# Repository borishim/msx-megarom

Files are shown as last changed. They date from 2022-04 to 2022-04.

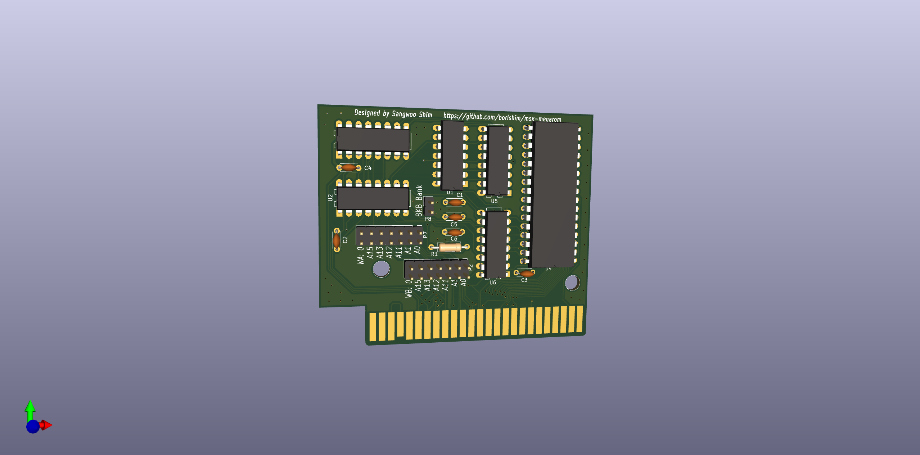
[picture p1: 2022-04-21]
megarom.png

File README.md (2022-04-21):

# msx-megarom
MSX megarom cartridge pcb (kicad)

There are three jumpers to set:
- P8: put a jumper for 8kB bank, otherwise 16kB
- P7 and P2: bank selection bits (WA and WB). Depends on the mapper type.

For example,
```
                           8kB WA  WB
                     ASC8: YES A11 A12
                    ASC16: NO  A12 0
                 Generic8: YES A13 A15
                Generic16: NO  A15 0
               Konami SCC: YES A13 A15
            Konami no SCC: YES A13 A15
Super Game World 30/64/80: YES A0  A1
            Super Pierrot: NO  A12 0
```
Also take a look https://www.msx.org/wiki/MegaROM_Mappers

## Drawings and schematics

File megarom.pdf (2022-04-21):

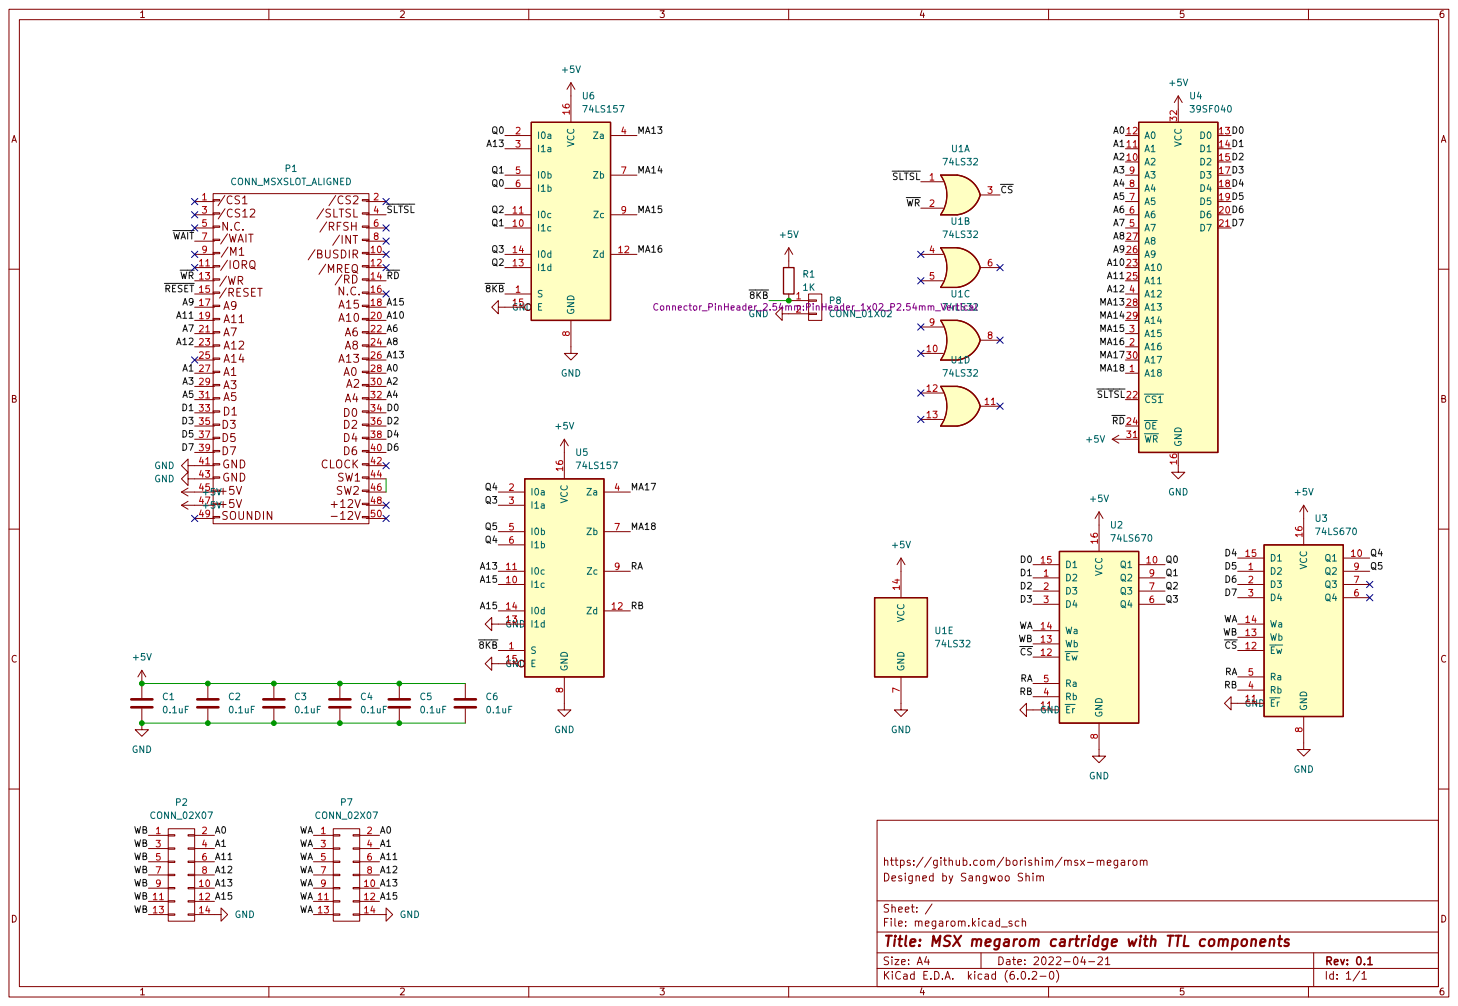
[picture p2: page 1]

https://github.com/borishim/msx-megarom
File: megarom.kicad_sch Sheet: / Designed by Sangwoo Shim

Id: 1/1 Title: MSX megarom cartridge with TTL components

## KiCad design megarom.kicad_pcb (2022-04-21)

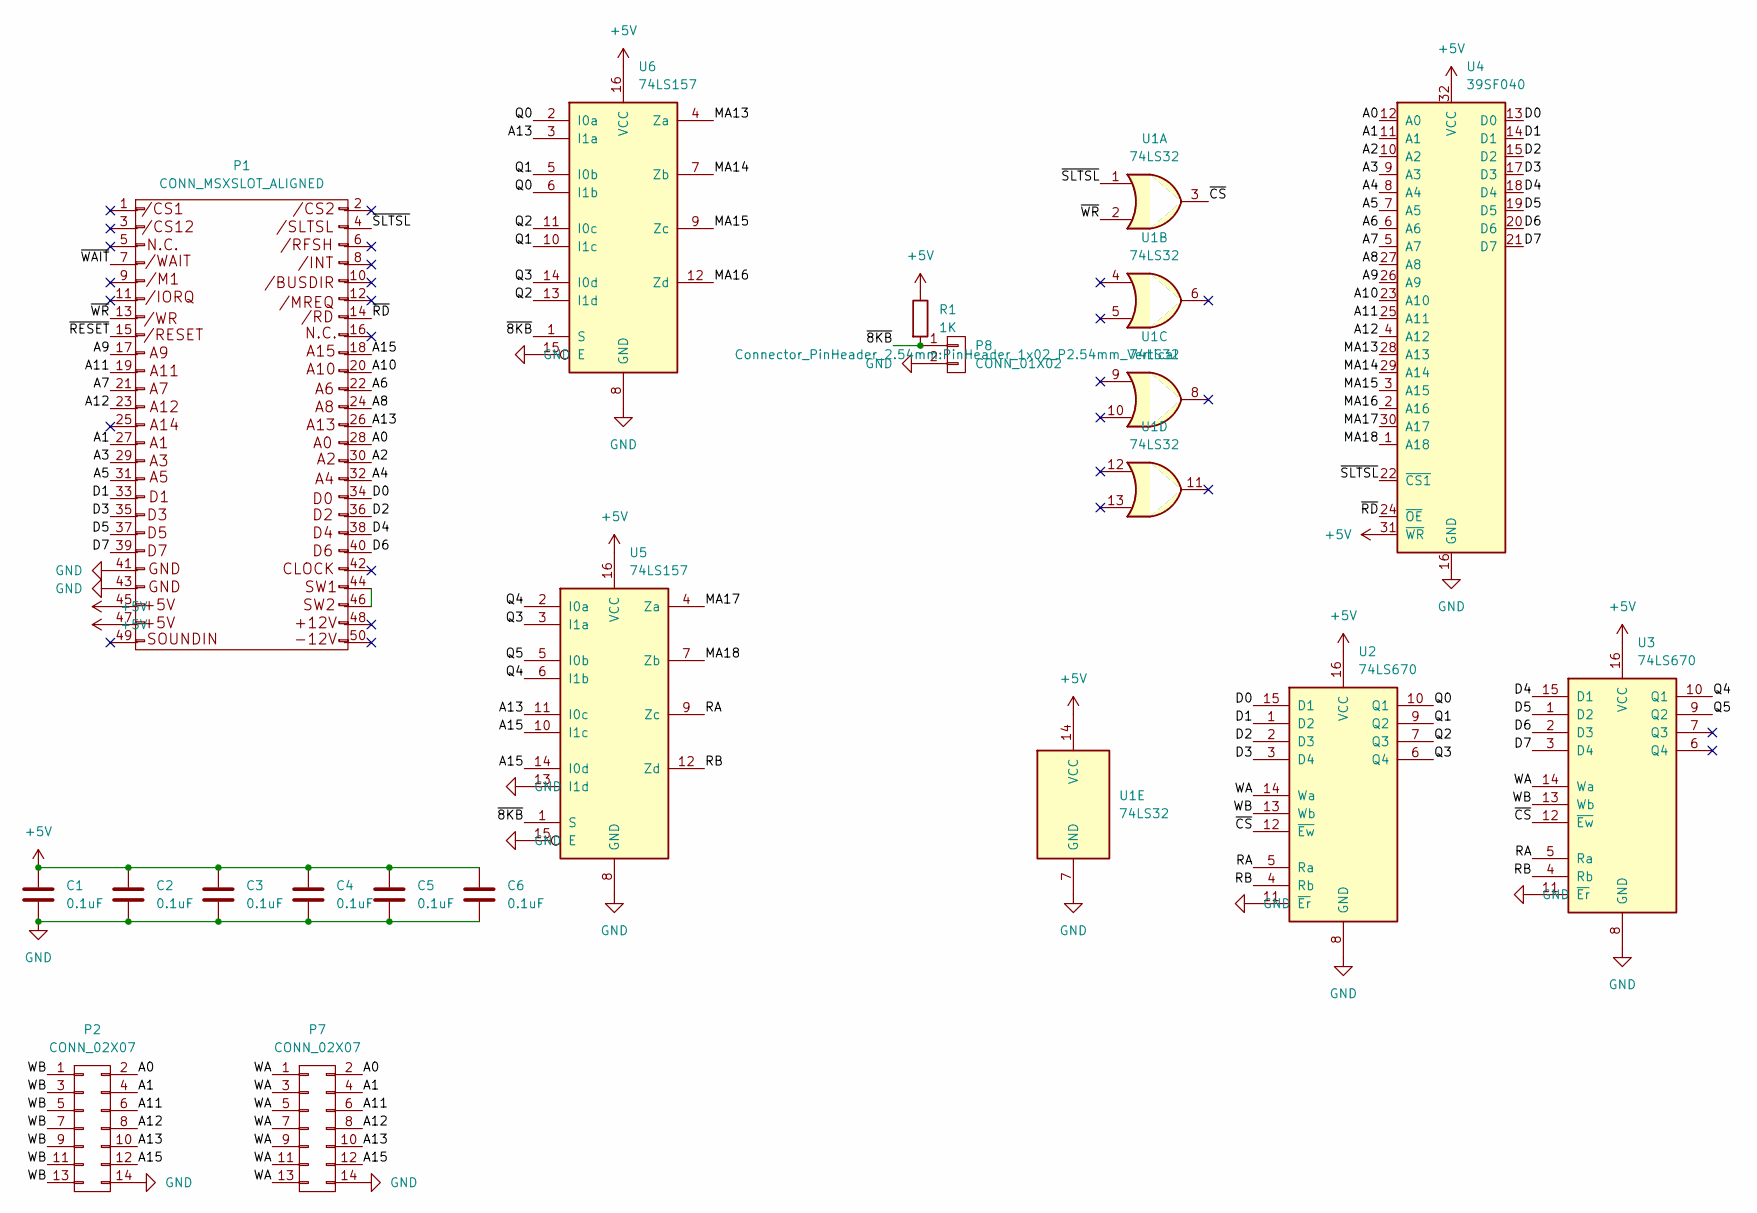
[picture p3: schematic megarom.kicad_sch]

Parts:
C1, C2, C3, C4, C5, C6: 0.1uF; C_Disc_D4.3mm_W1.9mm_P5.00mm
P1: CONN_MSXSLOT_ALIGNED; card_edge_connector
P2, P7: CONN_02X07; PinHeader_2x07_P2.54mm_Vertical
P8: CONN_01X02; PinHeader_1x02_P2.54mm_Vertical
R1: 1K; R_Axial_DIN0207_L6.3mm_D2.5mm_P10.16mm_Horizontal
U1: 74LS32; DIP-14_W7.62mm_LongPads
U2, U3: 74LS670; DIP-16_W7.62mm_LongPads
U4: 39SF040; DIP-32_W15.24mm_LongPads
U5, U6: 74LS157; DIP-16_W7.62mm_LongPads

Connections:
+5V: C1.1, C2.1, C3.1, C4.1, C5.1, C6.1, P1.45, P1.47, R1.1, U1.14 (VCC), U2.16 (VCC), U3.16 (VCC), U4.31 (~WR), U4.32 (VCC), U5.16 (VCC), U6.16 (VCC)
/A0: P1.28, P2.2, P7.2, U4.12 (A0)
/A1: P1.27, P2.4, P7.4, U4.11 (A1)
/A2: P1.30, U4.10 (A2)
/A3: P1.29, U4.9 (A3)
/A4: P1.32, U4.8 (A4)
/A5: P1.31, U4.7 (A5)
/A6: P1.22, U4.6 (A6)
/A7: P1.21, U4.5 (A7)
/A8: P1.24, U4.27 (A8)
/A9: P1.17, U4.26 (A9)
/A10: P1.20, U4.23 (A10)
/A11: P1.19, P2.6, P7.6, U4.25 (A11)
/A12: P1.23, P2.8, P7.8, U4.4 (A12)
/A13: P1.26, P2.10, P7.10, U5.11 (I0c), U6.3 (I1a)
/A15: P1.18, P2.12, P7.12, U5.10 (I1c), U5.14 (I0d)
/D0: P1.34, U2.15 (D1), U4.13 (D0)
/D1: P1.33, U2.1 (D2), U4.14 (D1)
/D2: P1.36, U2.2 (D3), U4.15 (D2)
/D3: P1.35, U2.3 (D4), U4.17 (D3)
/D4: P1.38, U3.15 (D1), U4.18 (D4)
/D5: P1.37, U3.1 (D2), U4.19 (D5)
/D6: P1.40, U3.2 (D3), U4.20 (D6)
/D7: P1.39, U3.3 (D4), U4.21 (D7)
/MA13: U4.28 (A13), U6.4 (Za)
/MA14: U4.29 (A14), U6.7 (Zb)
/MA15: U4.3 (A15), U6.9 (Zc)
/MA16: U4.2 (A16), U6.12 (Zd)
/MA17: U4.30 (A17), U5.4 (Za)
/MA18: U4.1 (A18), U5.7 (Zb)
/Q0: U2.10 (Q1), U6.2 (I0a), U6.6 (I1b)
/Q1: U2.9 (Q2), U6.5 (I0b), U6.10 (I1c)
/Q2: U2.7 (Q3), U6.11 (I0c), U6.13 (I1d)
/Q3: U2.6 (Q4), U5.3 (I1a), U6.14 (I0d)
/Q4: U3.10 (Q1), U5.2 (I0a), U5.6 (I1b)
/Q5: U3.9 (Q2), U5.5 (I0b)
/RA: U2.5 (Ra), U3.5 (Ra), U5.9 (Zc)
/RB: U2.4 (Rb), U3.4 (Rb), U5.12 (Zd)
/WA: P7.1, P7.3, P7.5, P7.7, P7.9, P7.11, P7.13, U2.14 (Wa), U3.14 (Wa)
/WB: P2.1, P2.3, P2.5, P2.7, P2.9, P2.11, P2.13, U2.13 (Wb), U3.13 (Wb)
/~8KB: P8.1, R1.2, U5.1 (S), U6.1 (S)
/~CS: U1.3, U2.12 (~Ew), U3.12 (~Ew)
/~RD: P1.14, U4.24 (~OE)
/~RESET: P1.15
/~SLTSL: P1.4, U1.1, U4.22 (~CS1)
/~WAIT: P1.7
/~WR: P1.13, U1.2
GND: C1.2, C2.2, C3.2, C4.2, C5.2, C6.2, P1.41, P1.43, P2.14, P7.14, P8.2, U1.7 (GND), U2.8 (GND), U2.11 (~Er), U3.8 (GND), U3.11 (~Er), U4.16 (GND), U5.8 (GND), U5.13 (I1d), U5.15 (E), U6.8 (GND), U6.15 (E)
unnamed: P1.44, P1.46

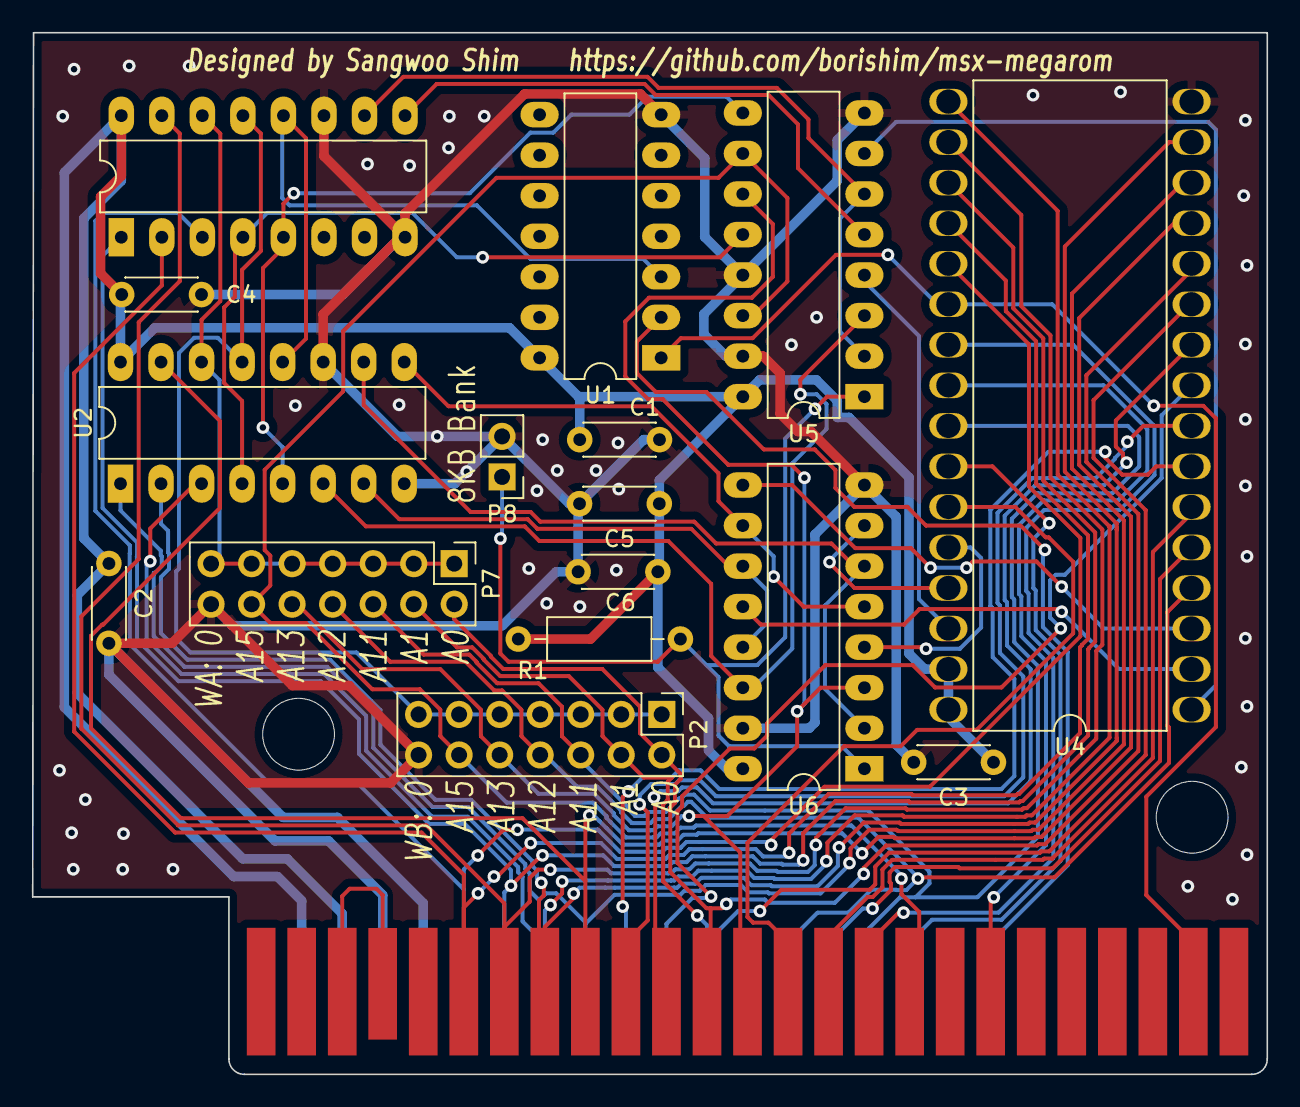
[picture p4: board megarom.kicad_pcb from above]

Board: 2 copper layers, 77.4 x 65.3 mm, 17 parts (0 on the bottom side), 47 nets.

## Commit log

2022-04-21 Added title, data, revision and comments to the schematics
    [megarom.kicad_sch]
2022-04-21 Updated schematics pdf
